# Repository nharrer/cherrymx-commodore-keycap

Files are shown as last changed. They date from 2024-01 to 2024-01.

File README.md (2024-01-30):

# Keycap with Commodore Logo and Cherry MX Stem in OEM Profile

The `.3mf` files are for Prusa Slicer and an Artillery Sidewinder X2.

The `.stl` files are in the [stl](stl) folder.

I printed them using Prusa Slicer on an Artillery Sidewinder X2 with a 0.4mm nozzle. A finer nozzle would yield better results. The inlay was printed with a 0.08mm layer height, while the key body has a variable layer height (0.08mm at the top part where the logo is and 0.2mm for the rest).

The stem is a bit recessed. So you need to support it (but only the base of the stem, not the whole inside).

This key fits perfectly on a Razer Blackwidow keyboard. You can customize and create your own key with OpenSCAD. Check out the [openscad](openscad/) folder.

<p float="left">
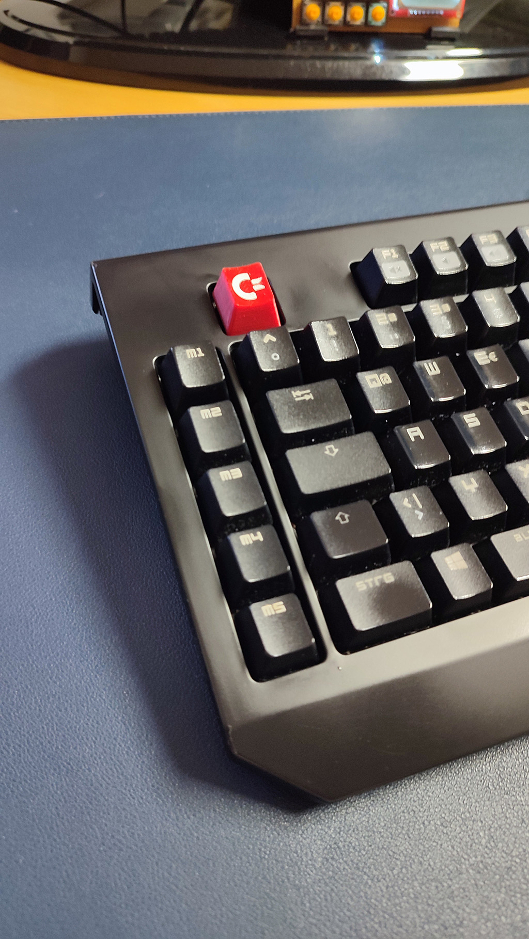
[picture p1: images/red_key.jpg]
Red Key
  
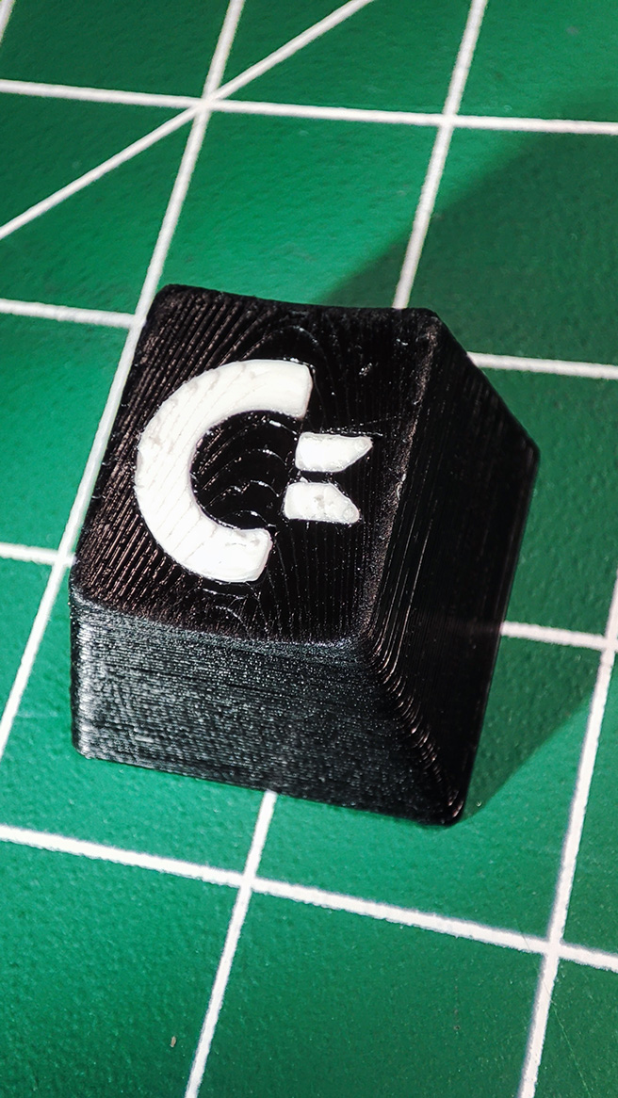
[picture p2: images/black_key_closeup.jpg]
Black Key Closeup
  
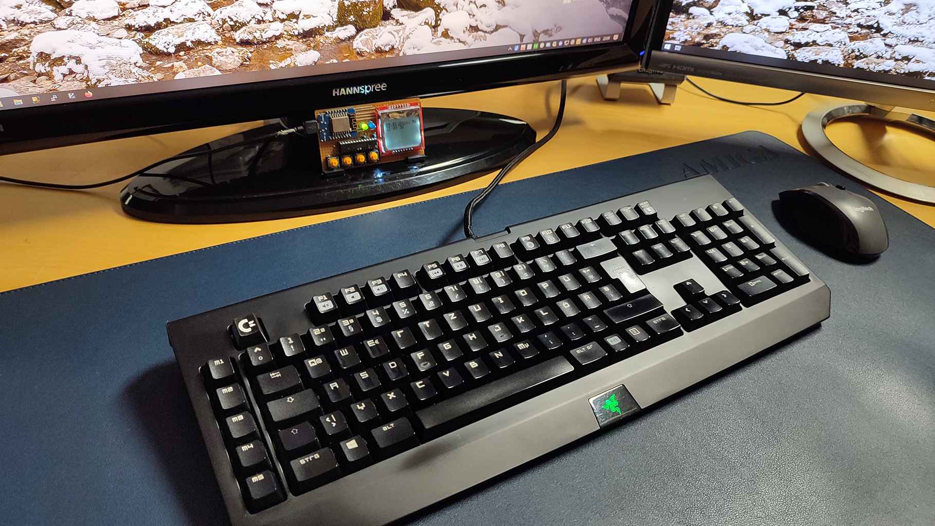
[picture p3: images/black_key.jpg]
Black Key
  
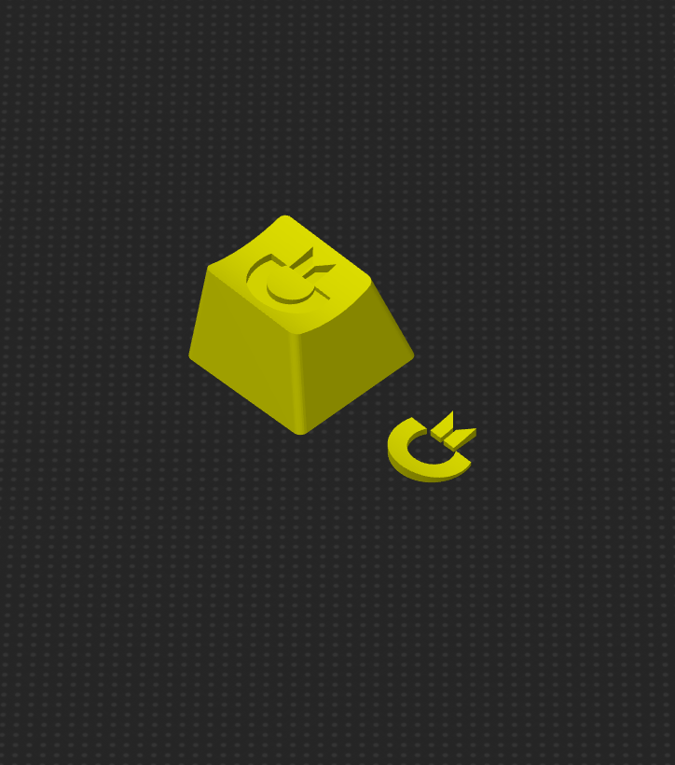
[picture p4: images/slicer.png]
Slicer
  
</p>

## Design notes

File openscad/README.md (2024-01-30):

# How to create your own keycap

1. Install [OpenSCAD](https://openscad.org/).
2. Clone [rsheldiii's](https://github.com/rsheldiii/KeyV2) excellent KeyV2 project into KeyV2

   ```git clone https://github.com/nharrer/KeyV2.git```

   (Note: There is currently a bug with recessed stems, so this is a patched fork - pull request is pending).
3. Open `commodore_key.scad` in OpenSCAD. Hit F6 and save the stl.

### Notes

- You might want to adjust `inlay_offset`, which is the space between the inlay and the key body. This might depend a lot upon your printer.
- `inlay_offset` only changes the size of the inlay. So if it is too tight or loose, you only need to export and print the inlay again. The body always stays the same.
- Change the parameters inside `c64key()`, if you want to create a different kind of keycap. Consult the [KeyV2](https://github.com/rsheldiii/KeyV2) repository on how to do that. The parameters I chose are for an OEM Profile key of row 5 (for the ESC key) with a Cherry MX stem with a recessed stem. The key fits perfectly into my Razer Blackwidow keyboard.

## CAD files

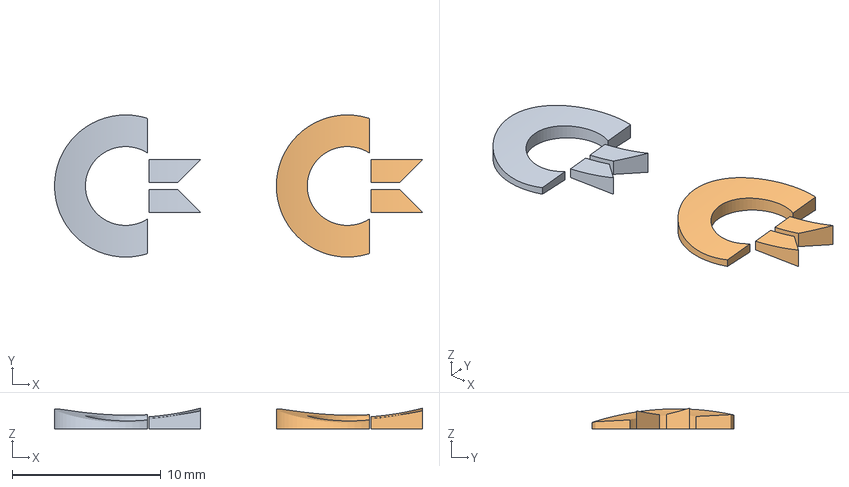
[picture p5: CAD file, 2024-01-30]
esc_commodore_inlay.3mf
24.7 x 9.56 x 1.40 mm
esc_commodore_inlay.stl x 2

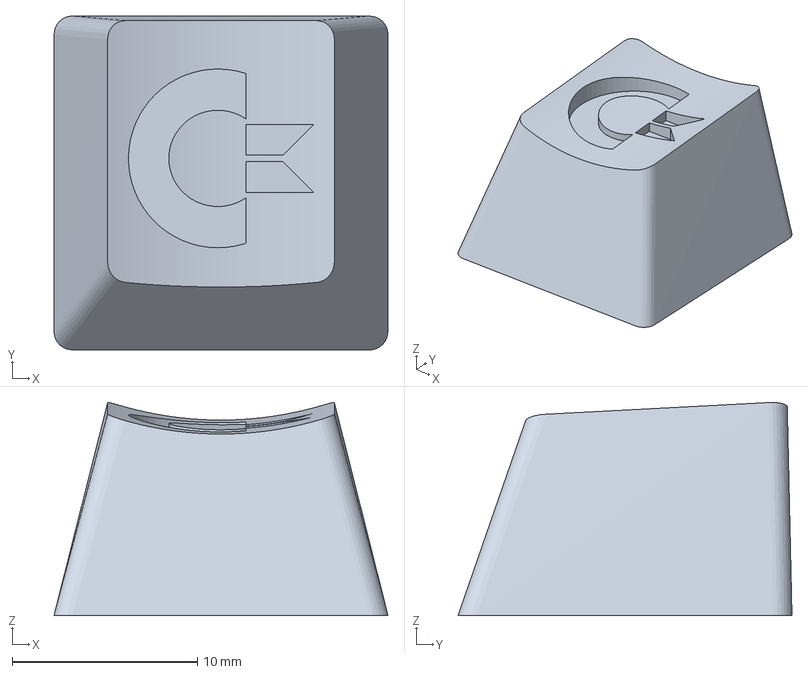
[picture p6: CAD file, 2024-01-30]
esc_commodore_key.3mf
18.0 x 18.0 x 11.5 mm

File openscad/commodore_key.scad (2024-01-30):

use <./commodore_logo.scad>
include <./KeyV2/includes.scad>

inlay_height = 2;
inlay_offset = 0.05;

module c64key() {
    $stem_slop = 0.30;
    $stem_inner_slop = 0.4;
    $support_type = "flared";
    $stem_support_type = "disable";
    //$stem_inset = 2;
    oem_row(5) key();
}

module c64logo(offset=0) {
    translate([0, 1.5, 9.5])
    linear_extrude(height=inlay_height)
    offset(delta=offset)
    logo(10);
}

module body() {
    difference() {
        c64key();
        c64logo();
    }
}

module inlay() {
    translate([0, 0, -9.5])
    intersection() {
        c64key();
        c64logo(-inlay_offset);
    }
}

// uncomment accordingly, for which part you want to render:
body();
//inlay();

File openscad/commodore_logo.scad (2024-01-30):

// Commodore Business Machines Logo by Chris Yaneff (1965)
// scruss - 2018
// from https://twitter.com/vccmalta/status/1066231884911468544

module logo(size=100) {
    a=size; // 10 cm
    b=0.034*a;
    c=0.166*a;
    d=0.30*a;
    e=0.364*a;
    f=0.52*a;
    g=0.53*a; // central hole is slightly elliptical
    h=a-e;
    i=b+2*(d+c);
    $fn=64;

    
    translate([-a/2, -a/2, 0])
    union() {
        difference() {
            translate([i/2,i/2]) difference() {
                circle(d=i);
                scale([g/f,f/f]) circle(d=f);
            }
            translate([h,0])square(a);
        }
        polygon([
            [h, i-d-c],
            [h, i-d],
            [a, i-d],
            [a-c, i-d-c]
        ]);
        polygon([
            [h, d],
            [h, d+c],
            [a-c, d+c],
            [a, d]
        ]);
    }
}

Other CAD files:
stl/esc_commodore_inlay.stl
stl/esc_commodore_key.stl
